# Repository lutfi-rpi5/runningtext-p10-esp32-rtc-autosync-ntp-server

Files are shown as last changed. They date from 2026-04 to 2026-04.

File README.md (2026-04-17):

# Running Text P10 ESP32 + RTC + Auto Sync NTP Server

**Detailed Engineering Design (DED) – Embedded System Engineer**

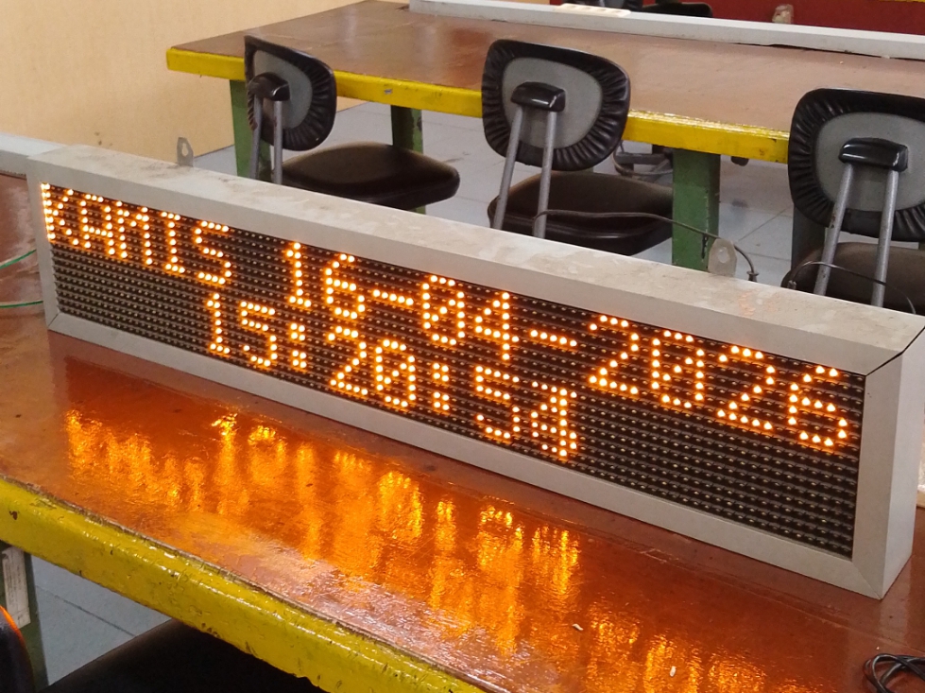
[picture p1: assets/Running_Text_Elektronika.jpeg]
Demo Sistem


---

## 1. Tentang Sistem

Sistem ini adalah **Running Text LED P10 berbasis ESP32** yang dirancang sebagai papan informasi digital cerdas. Keunggulan utamanya adalah ketahanan terhadap gangguan internet: display tetap menampilkan teks berjalan dan waktu dari **RTC (Real-Time Clock)** meskipun jaringan Wi-Fi tidak tersedia. Ketika koneksi internet kembali, sistem akan **secara otomatis menyinkronkan waktu dari server NTP (Network Time Protocol)** dan menyimpannya ke modul RTC, memastikan akurasi waktu yang tinggi tanpa campur tangan pengguna.

Sistem dibangun dengan pendekatan **non-blocking** pada seluruh operasi (Wi-Fi, NTP, display), sehingga running text tetap berjalan lancar tanpa jeda yang mengganggu. Arsitektur modular memisahkan logika display, RTC, sinkronisasi NTP, dan buzzer ke dalam file terpisah, memudahkan pengembangan dan pemeliharaan.

**Target Aplikasi:**

- Papan informasi kampus, sekolah, atau institusi.
- Display jam digital di ruang publik (lobi, koridor).
- Papan pengumuman di bengkel, laboratorium, atau area produksi.
- Sistem signage mandiri dengan ketergantungan internet minimal.

---

## 2. Identitas Programmer

| **Atribut** | **Detail** |
|---|---|
| **Nama** | Muhammad Lutfi Nur Anendi |
| **GitHub** | [lutfi-rpi5](https://github.com/lutfi-rpi5) |
| **Board Target** | ESP32 WROOM-32 (ESP32 Dev Module v1.0.6) |
| **Tanggal Rilis** | 3 April 2026 |
| **Versi Firmware**  | 1.0.0 (Stable) |
| **Lisensi** | MIT |

---

## 3. Fitur Sistem

| **Fitur** | **Deskripsi** |
|---|---|
| **Running Text LED P10** | Mendukung panel P10 *single-color* dengan konfigurasi dimensi yang dapat diatur (`DISPLAYS_ACROSS`, `DISPLAYS_DOWN`). |
| **RTC Offline Mode** | Waktu tetap akurat menggunakan modul RTC DS1302/DS3231 saat tidak ada internet. |
| **Auto Sync NTP Server** | Sinkronisasi waktu otomatis setiap interval tertentu (default 60 menit) ketika Wi-Fi tersedia. |
| **Non-blocking Architecture** | Semua operasi (Wi-Fi, NTP, display) berjalan tanpa memblokir *main loop*, menjamin running text tetap halus. |
| **Fallback Otomatis ke RTC** | Jika NTP gagal atau internet putus, sistem langsung beralih ke RTC tanpa mengganggu tampilan. |
| **Scene Management** | Mendukung dua *scene* utama: **Scene 1 (Running Text)** dan **Scene 2 (Display RTC)** dengan transisi otomatis.|
| **Durasi Tampil RTC Dapat Dikonfigurasi** | Waktu tampil scene RTC dapat diatur dalam milidetik (default 3 menit). |
| **Buzzer Feedback** | Indikator suara untuk *boot*, sinkronisasi berhasil, dan *error*. |
| **Konfigurasi Mudah via Kode** | Semua parameter (SSID, password, zona waktu, kecepatan scroll, dll.) terpusat di file `.ino` dan `.cpp`. |
| **Modular Code** | Pemisahan modul `RunningText`, `RTCAutoSync`, `Buzzer`, dan `virtuabotixRTC` untuk kemudahan *debugging* dan pengembangan. |

---

## 4. Arsitektur Sistem

Diagram blok berikut menggambarkan aliran data dan kontrol utama:

```
+----------------+      +----------------+      +----------------+
|   Internet     |      |   ESP32        |      |   LED Panel    |
|   (NTP Server) |<---->|   (Wi-Fi)      |<---->|   P10          |
+----------------+      +----------------+      +----------------+
                              ^   ^
                              |   |
                              v   v
                         +----------------+
                         |   RTC Module   |
                         |   (DS1302)     |
                         +----------------+
                              ^
                              |
                              v
                         +----------------+
                         |   Buzzer       |
                         |   (Feedback)   |
                         +----------------+
```

**Alur Kerja Sistem:**

1. **ESP32 Boot** – Inisialisasi Serial, Buzzer, RTC, dan Display.
2. **Coba Koneksi Wi-Fi** – Dilakukan secara *non-blocking* setelah *boot delay* (default 0 detik).
3. **Jika Berhasil → Sync NTP** – Waktu dari `pool.ntp.org` diambil, dikonversi ke zona waktu WIB (GMT+7), dan disimpan ke RTC.
4. **Jika Gagal → Gunakan RTC** – Sistem tetap beroperasi dengan waktu yang tersimpan di RTC.
5. **Running Text Berjalan** – Scene teks utama ditampilkan (berulang 1x), lalu beralih ke scene RTC selama durasi tertentu, dan kembali ke scene teks.
6. **Sinkronisasi Berkala** – Setiap interval `ntp_sync_interval` (default 60 menit), sistem kembali mencoba sinkronisasi NTP.

**Penanganan Kegagalan:**

- **Wi-Fi Timeout** – Setelah 60 detik tanpa koneksi, Wi-Fi dimatikan untuk menghemat daya.
- **NTP Failed** – RTC tetap digunakan, dan sinkronisasi dicoba lagi pada interval berikutnya.

---

## 5. Hardware Requirements

| **Komponen** | **Spesifikasi / Catatan** |
|---|---|
| **ESP32** | ESP32 WROOM-32 (disarankan) atau varian ESP32 lain dengan pinout serupa. |
| **LED Panel P10** | *Single-color* (merah/hijau/biru), resolusi 32x16 pixel per panel. |
| **RTC Module** | DS1302 (diuji) atau DS3231 (kompatibel). Pastikan baterai CR2032 terpasang untuk backup. |
| **Power Supply** | 5V DC dengan arus cukup (min. 2A untuk 1-3 panel, lebih besar untuk panel lebih banyak). |
| **Kabel Jumper** | Male-to-female dan female-to-female untuk koneksi ESP32 ↔ P10 ↔ RTC. |
| **Buzzer (Opsional)** | Buzzer aktif LOW 5V. |
| **Konektor** | Header pin 2.54mm untuk koneksi yang rapi. |

---

## 6. Software Requirements

| **Software** | **Versi / Catatan** |
|---|---|
| **Arduino IDE** | 1.8.19 atau lebih baru. |
| **ESP32 Board Package** | **Versi 1.0.6** (wajib). Versi lain mungkin menyebabkan error kompilasi pada library DMD32. |
| **Library DMD32 v1.0** | Instal via Library Manager Arduino IDE. |
| **Library Bawaan ESP32** | `WiFi.h`, `time.h`, `SPI.h`, `Wire.h` (sudah termasuk dalam board package). |
| **Library Lokal (Include)** | `runningtext.h/cpp`, `rtc_autosync.h/cpp`, `virtuabotixRTC.h/cpp`, `buzzer.h/cpp` (sudah ada di repo).  |
| **Fonts** | `SystemFont5x7.h`, `Arial_black_16.h` (termasuk dalam library DMD32). |

---

## 7. Installation

### 7.1 Clone Repository

```bash
git clone https://github.com/lutfi-rpi5/runningtext-p10-esp32-rtc-autosync-ntp-server.git
```
Atau unduh ZIP dari GitHub dan ekstrak.

### 7.2 Install ESP32 Board Package v1.0.6
1. Buka **Arduino IDE** → **File** → **Preferences**.
2. Tambahkan URL berikut ke **Additional Boards Manager URLs**:
```text
https://raw.githubusercontent.com/espressif/arduino-esp32/gh-pages/package_esp32_index.json
```
3. Buka **Tools** → **Board** → **Boards Manager**.
4. Cari **ESP32** by Espressif Systems dan instal **versi 1.0.6**.

### 7.3 Install Library DMD32
1. Buka **Sketch** → **Include Library** → **Manage Libraries**.
2. Cari **DMD32** dan install **versi 1.0**.

### 7.4 Buka Project
1. Buka file `runningtext-p10-esp32-rtc-autosync-ntp-server.ino` di **Arduino IDE**.
2. Pastikan board yang dipilih adalah **ESP32 Dev Module** (atau sesuai board Anda).

### 7.5 Compile & Upload
1. Hubungkan ESP32 ke komputer via USB.
2. Pilih port yang sesuai di **Tools** → **Port**.
3. Klik tombol **Upload**.

---

## 8. Configurations
Seluruh konfigurasi penting terpusat di file utama `.ino` dan file modul terkait. Berikut panduan lengkapnya.

### 8a. Sinkronisasi RTC (NTP Sync Interval)
**Lokasi**: `rtc_autosync.cpp` baris 11-13.

```cpp
const unsigned long ntp_sync_interval = (60 * 60) * 1000;  // 60 menit
const unsigned long ntp_sync_starting_at = (0.1 * 60) * 1000; // 10 detik pertama
```

* `ntp_sync_interval` : Interval sinkronisasi NTP dalam milidetik. Default 1 jam.
* `ntp_sync_starting_at` : Delay awal sebelum sinkronisasi pertama setelah boot. Default 10 detik (untuk memberi waktu koneksi Wi-Fi stabil).

### 8b. Time Zone & Day Offset Setting
**Lokasi**: `rtc_autosync.cpp` baris 9-10.

```cpp
const long gmtOffset_sec = 25200;   // WIB (GMT+7) = 7 * 3600 detik
const int daylightOffset_sec = 0;   // Tidak ada DST di Indonesia
```

* `gmtOffset_sec` : Offset zona waktu dalam detik dari GMT.
    * WIB (GMT+7) = 25200
    * WITA (GMT+8) = 28800
    * WIT (GMT+9) = 32400
* `daylightOffset_sec` : Offset Daylight Saving Time (tidak digunakan di Indonesia).

### 8c. SSID & PASSWORD Setting
**Lokasi**: `rtc_autosync.cpp` baris 8.

```cpp
const char* ssid = "sync-elektro";
const char* password = "12345678";
```
Ganti dengan kredensial Wi-Fi yang tersedia.

### 8d. Jumlah Display Across & Display Down
**Lokasi**: `runningtext.cpp` baris 9.

```cpp
#define DISPLAYS_ACROSS 3   // Jumlah panel horizontal
#define DISPLAYS_DOWN 1     // Jumlah panel vertikal
```
Atur sesuai konfigurasi fisik panel P10 Anda. Sistem akan otomatis menyesuaikan lebar total display (`32 * DISPLAYS_ACROSS` pixel).

### 8e. Ganti Text Utama
**Lokasi**: `runningtext-p10-esp32-rtc-autosync-ntp-server.ino` baris 8-10.

```cpp
String text_utama = "Selamat Datang di Bengkel Jurusan Teknik Elektro | Prodi Teknik Elektronika Politeknik Negeri Sriwijaya Utamakan Keselamatan dan Kesehatan Kerja";
```
Ganti dengan teks yang diinginkan. Gunakan karakter `|` sebagai pemisah jika ingin beberapa bagian teks (tidak memengaruhi animasi, hanya teks biasa).

### 8f. Display Speed
**Lokasi**: `runningtext-p10-esp32-rtc-autosync-ntp-server.ino` baris 12.

```cpp
display.setSpeed(20);
```
* Nilai dalam milidetik, semakin kecil semakin cepat. Rentang tipikal 15–50.

### 8g. Durasi Tampil Scene RTC
**Lokasi**: `runningtext-p10-esp32-rtc-autosync-ntp-server.ino` baris 22-23.

```cpp
display.sceneRTC( tanggal, waktu, (3 * 60) * 1000 ); // 3 menit
```
* Ubah (3 * 60) * 1000 menjadi durasi yang diinginkan dalam milidetik. Contoh:
    * 1 menit = (1 * 60) * 1000
    * 5 menit = (5 * 60) * 1000

---

## 9. Pin Configuration

### 9.1 Panel P10 → ESP32

|**P10 Pin**  |	**ESP32 GPIO** |  **Keterangan**  |
|---|---|---|
|GND | GND |	Ground |
|OE	 | GPIO 22 |Output Enable |
|A	 | GPIO 19 |Address Line A|
|B	 | GPIO 21	 |Address Line B|
|CLK	  | GPIO 18	 |Clock (Shift Register)|
|LAT (STB)|	GPIO 2	 |Latch / Strobe|
|DR (R1)  | GPIO 23	 |Data Red (untuk panel single-color)|

**Catatan**: Untuk panel *single-color*, hanya gunakan pin **R1** (DR). Pin **G1** (hijau) dan **B1** (biru) tidak digunakan.

### 9.2 RTC (DS1302) → ESP32
|**DS1302 Pin** |	**ESP32 GPIO**  |
|---|---|
|CLK	 | GPIO 25 |
|DAT	 | GPIO 26 |
|RST	 | GPIO 27 |
|VCC	 |5V (atau 3.3V) |
|GND	 | GND |

### 9.3 Buzzer → ESP32
|Buzzer Pin	 | ESP32 GPIO  |
|---|---|
|+ (Positif) |	GPIO 33 |
|- (Negatif) |	GND |

**Catatan**: Buzzer dikonfigurasi active *LOW* (menyala saat pin diberi logika `LOW`). Jika menggunakan buzzer langsung tanpa relay, ubah logika di `buzzer.cpp` baris 4-5 sesuai komentar.

---

## 10. Struktur Proyek
```text
runningtext-p10-esp32-rtc-autosync-ntp-server/
│
├── runningtext-p10-esp32-rtc-autosync-ntp-server.ino   # Main sketch
├── runningtext.h / .cpp                                # Modul display & scene
├── rtc_autosync.h / .cpp                               # Modul RTC & NTP sync
├── virtuabotixRTC.h / .cpp                             # Library RTC DS1302
├── buzzer.h / .cpp                                     # Modul buzzer
├── fonts/
│   ├── SystemFont5x7.h
│   └── Arial_black_16.h
├── build/                                              # Compiled firmware (opsional)
└── README.md
```

---

## 11. Troubleshooting

| **Masalah** | **Solusi** |
|---|---|
| **Display tidak menyala / blank** | - Periksa koneksi kabel P10 (OE, CLK, LAT, DR).<br>- Pastikan power supply 5V mencukupi (gunakan adaptor eksternal, bukan USB ESP32). |
| **Teks berjalan terlalu cepat/lambat** | Ubah nilai `display.setSpeed()` di file `.ino`. Semakin kecil nilai, semakin cepat. |
| **Waktu RTC tidak akurat / reset** | - Ganti baterai CR2032 pada modul RTC.<br>- Pastikan sinkronisasi NTP berhasil (lihat Serial Monitor). |
| **Wi-Fi tidak terhubung** | - Periksa SSID dan password di `rtc_autosync.cpp`.<br>- Pastikan sinyal Wi-Fi cukup kuat.<br>- Tambahkan `delay(5000)` setelah `WiFi.begin()`. |
| **ESP32 bootloop (restart terus pada saat di Serial Monitor)** | **Solusi Umum:** <br>- Buka Serial Monitor (baud 115200) dan periksa pesan error terakhir.<br>- Coba *flash* ulang firmware sambil menekan tombol **BOOT**.<br>- Pastikan power supply stabil (3.3V/5V) dan tidak ada korsleting pada pin GPIO.<br>- Hapus flash sepenuhnya dengan `esptool.py erase_flash` lalu upload ulang.<br><br>**Solusi Alternatif (Khusus Windows User – Pembersihan Cache & Instal Ulang Board Package):** <br>1. Buka **Board Manager** di Arduino IDE, cari **ESP32** by Espressif Systems, lalu klik **Remove** untuk menghapus versi yang terpasang (misal v1.0.6).<br>2. Tutup **semua jendela** Arduino IDE yang sedang berjalan.<br>3. Tekan tombol <kbd>Win</kbd> + <kbd>R</kbd>, ketik `%TEMP%` lalu tekan **Enter**. Pilih semua file dan folder (<kbd>Ctrl</kbd> + <kbd>A</kbd>) kemudian hapus permanen dengan <kbd>Shift</kbd> + <kbd>Delete</kbd>.<br>4. Ulangi langkah 3 untuk direktori **`temp`** dan **`PREFETCH`** (ketik masing‑masing pada dialog **Run**).<br>5. **Restart** komputer/laptop.<br>6. Buka kembali Arduino IDE, instal ulang **ESP32 Board Package versi 1.0.6** melalui Board Manager.<br>7. Coba upload ulang sketch. |
| **Kompilasi error "DMD was not declared"** | Pastikan library **DMD32** sudah terinstal. Jika tetap error, coba hapus dan instal ulang library. |
| **ESP32 tidak terdeteksi di Arduino IDE** | - Tekan tombol BOOT saat uploading.<br>- Instal driver USB-to-Serial (CP210x atau CH340). |

## 12. Pengembangan Lebih Lanjut
* **OTA Update**: Tambahkan fitur Over-the-Air untuk update firmware via Wi-Fi.
* **Multi-Scene**: Tambahkan lebih banyak scene (misal: suhu, kelembaban, atau informasi dari sensor).
* **Web Config**: Buat portal web sederhana untuk mengubah teks dan pengaturan tanpa recompile.
* **E-paper / OLED**: Integrasi display sekunder untuk informasi status sistem.

---

## 13. Kontribusi
Kontribusi dalam bentuk pull request atau issue sangat diterima. Pastikan kode mengikuti gaya penulisan yang konsisten dan terdokumentasi dengan baik.

## 14. Lisensi
Proyek ini dilisensikan di bawah **MIT License**. Silakan gunakan, modifikasi, dan distribusikan sesuai kebutuhan.

**Dokumentasi ini disusun berdasarkan analisis menyeluruh terhadap kode sumber, struktur proyek, dan best practice _embedded system engineering_. Untuk pertanyaan lebih lanjut, silakan buka _issue_ di repositori GitHub.**

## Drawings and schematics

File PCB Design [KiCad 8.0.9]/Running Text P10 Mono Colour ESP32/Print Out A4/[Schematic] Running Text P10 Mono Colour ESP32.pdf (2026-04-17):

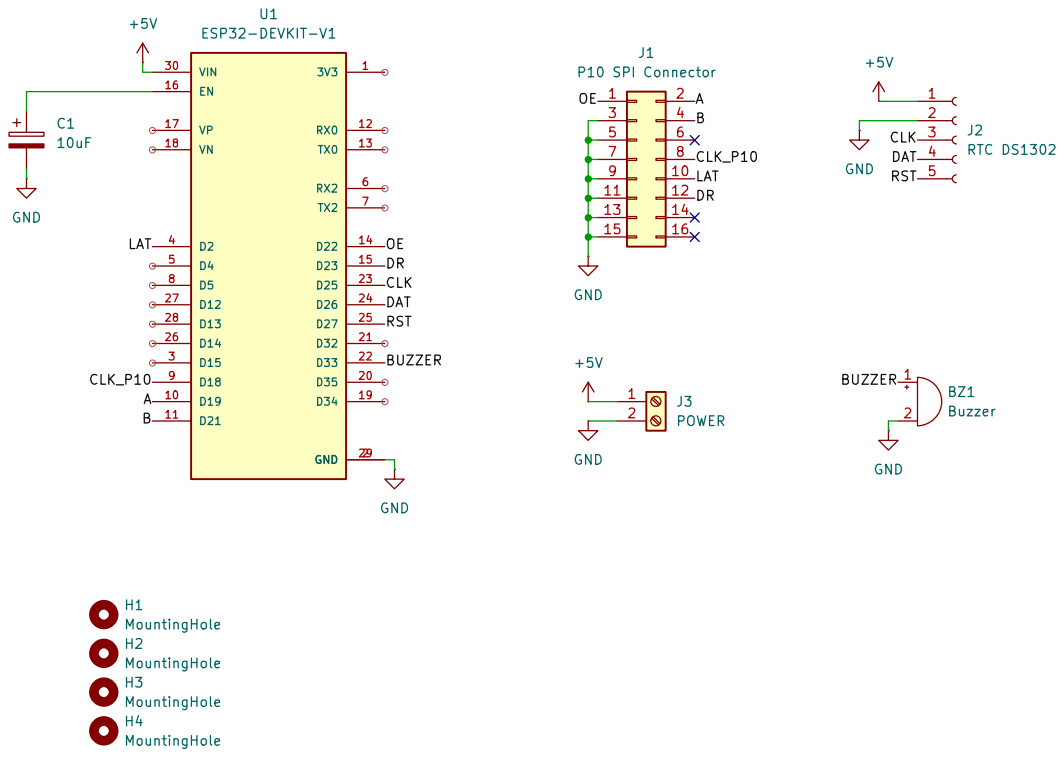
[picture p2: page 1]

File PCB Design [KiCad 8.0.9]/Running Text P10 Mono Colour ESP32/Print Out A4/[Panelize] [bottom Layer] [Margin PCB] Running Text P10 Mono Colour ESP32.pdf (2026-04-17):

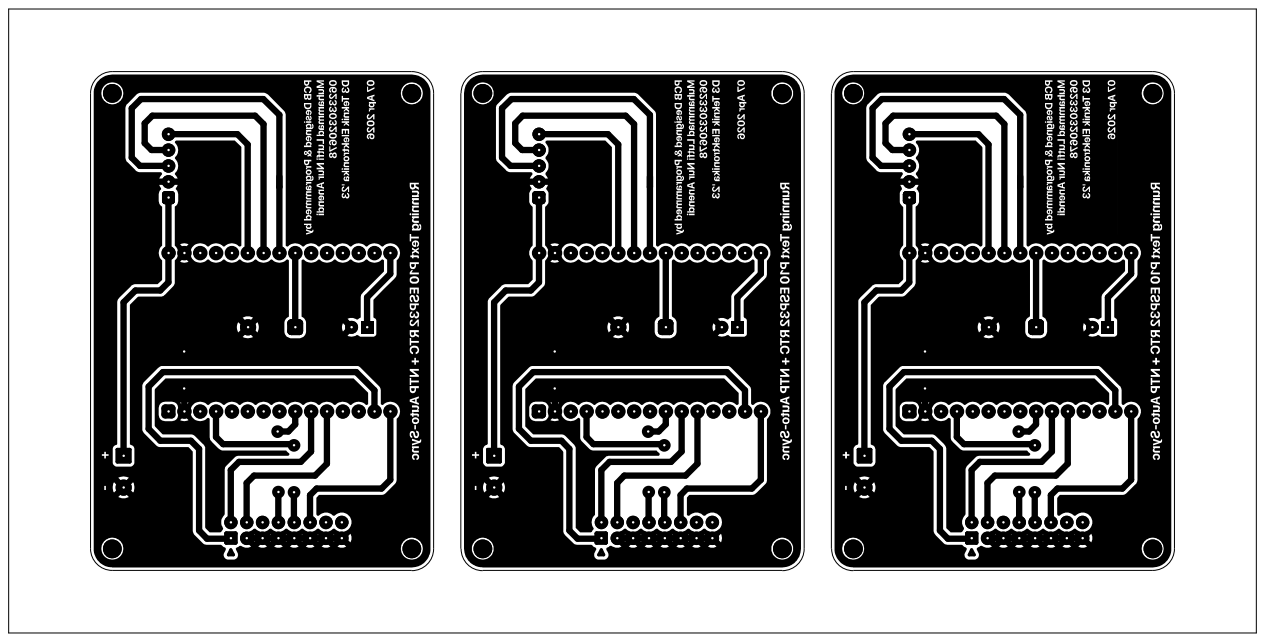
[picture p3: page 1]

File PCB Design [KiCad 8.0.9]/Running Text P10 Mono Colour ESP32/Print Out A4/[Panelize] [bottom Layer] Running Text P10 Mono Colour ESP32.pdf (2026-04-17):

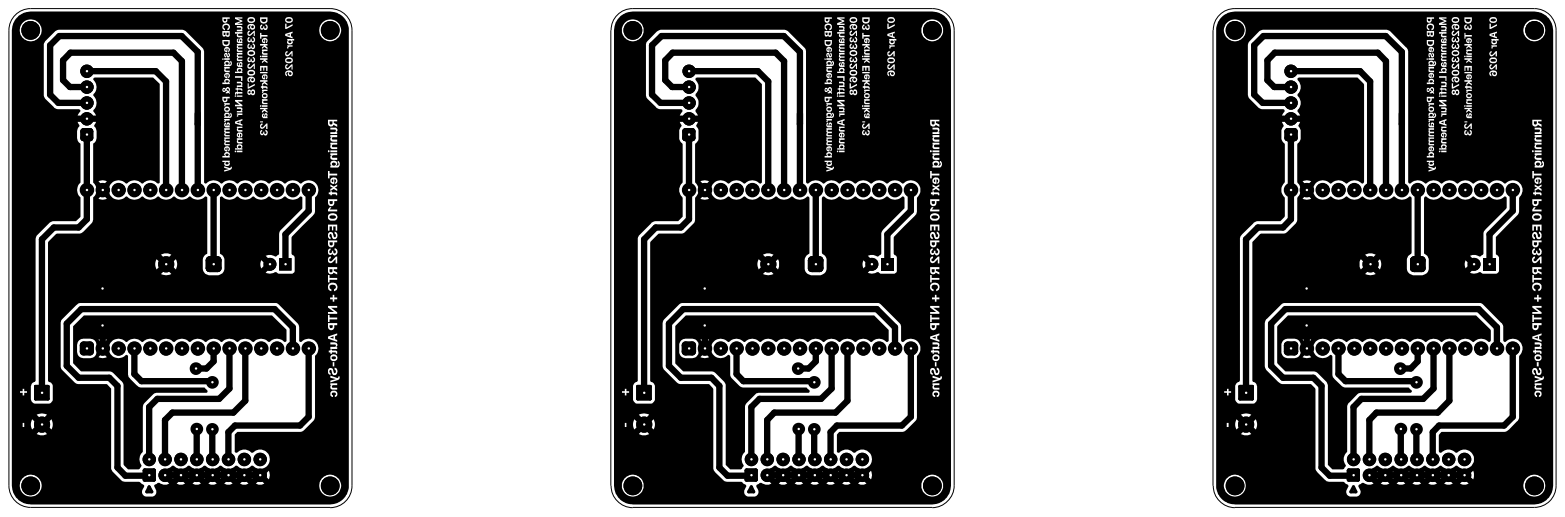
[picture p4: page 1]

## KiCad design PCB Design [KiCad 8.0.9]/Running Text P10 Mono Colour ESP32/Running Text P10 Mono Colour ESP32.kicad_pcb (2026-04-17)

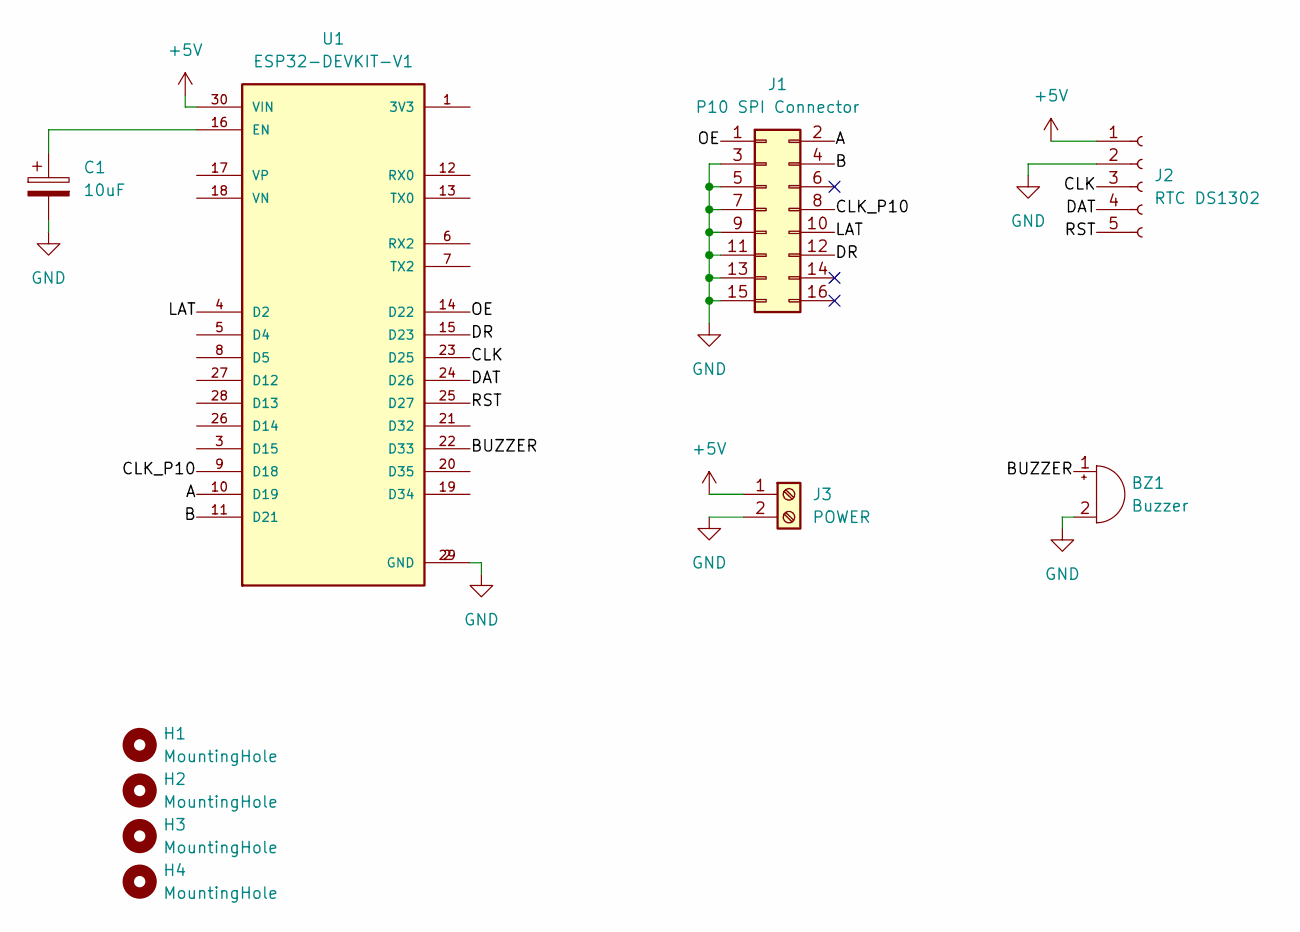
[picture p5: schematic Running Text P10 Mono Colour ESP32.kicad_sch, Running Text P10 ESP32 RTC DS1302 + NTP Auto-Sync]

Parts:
BZ1: Buzzer; Buzzer_12x9.5RM7.6
C1: 10uF; CP_Radial_D5.0mm_P2.50mm
H1, H2, H3, H4: MountingHole; MountingHole_3mm
J1: P10 SPI Connector; IDC-Header_2x08_P2.54mm_Vertical
J2: RTC DS1302; PinHeader_1x05_P2.54mm_Vertical
J3: POWER; TerminalBlock_RND_205-00232_1x02_P5.08mm_Horizontal
U1: ESP32-DEVKIT-V1; ESP32_DEVKIT_V1; PARTREV N/A

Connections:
+5V: J2.1, J3.1, U1.30 (VIN)
/A: J1.2, U1.10 (D19)
/B: J1.4, U1.11 (D21)
/BUZZER: BZ1.1 (+), U1.22 (D33)
/CLK: J2.3, U1.23 (D25)
/CLK_P10: J1.8, U1.9 (D18)
/DAT: J2.4, U1.24 (D26)
/DR: J1.12, U1.15 (D23)
/LAT: J1.10, U1.4 (D2)
/OE: J1.1, U1.14 (D22)
/RST: J2.5, U1.25 (D27)
GND: BZ1.2 (-), C1.2, J1.3, J1.5, J1.7, J1.9, J1.11, J1.13, J1.15, J2.2, J3.2, U1.2 (GND), U1.29 (GND)
unnamed: C1.1, U1.16 (EN)

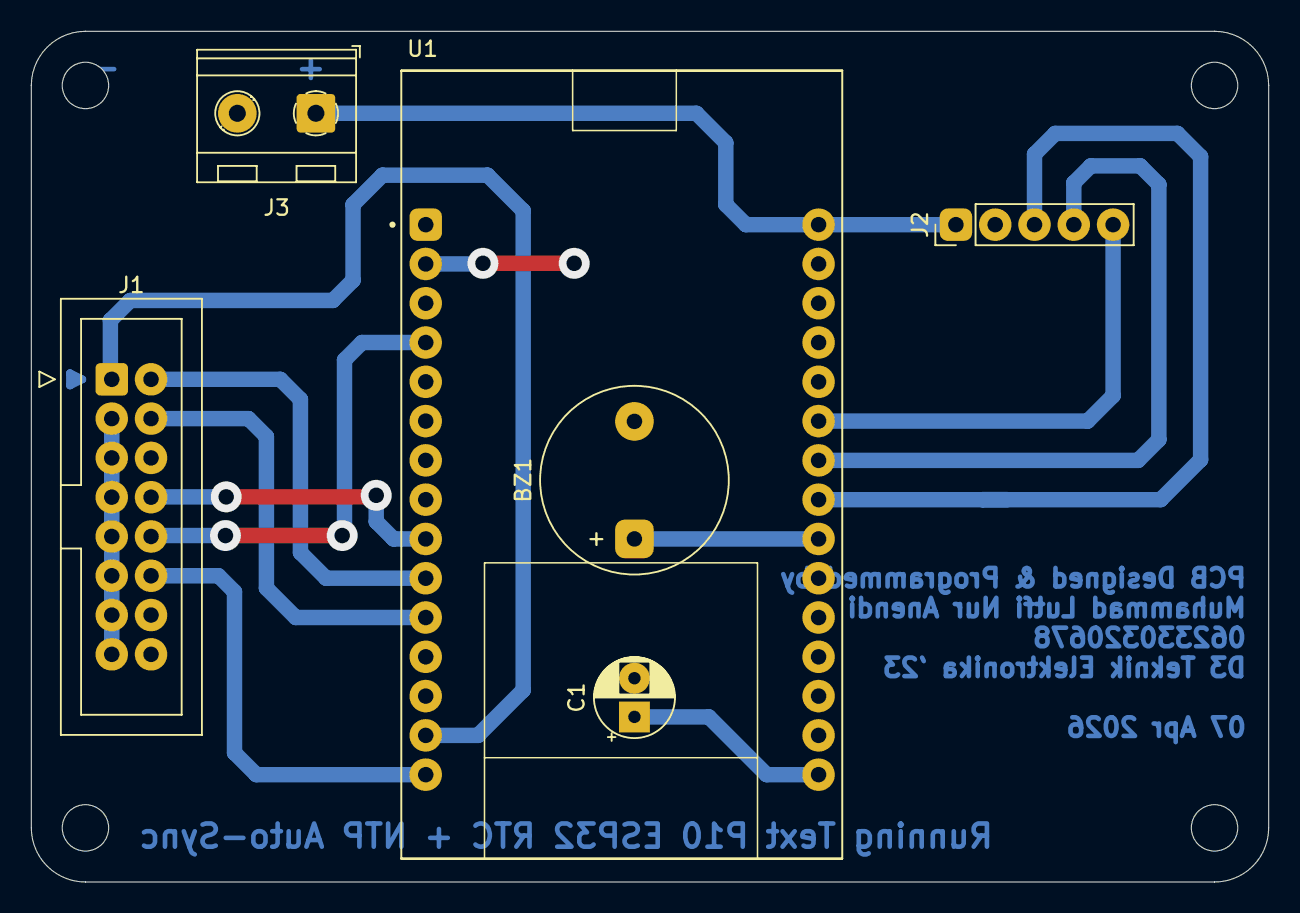
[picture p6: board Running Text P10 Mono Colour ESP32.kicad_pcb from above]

Board: 2 copper layers, 80.0 x 55.0 mm, 10 parts (0 on the bottom side), 13 nets.

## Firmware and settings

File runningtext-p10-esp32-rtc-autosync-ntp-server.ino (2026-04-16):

/*
PROGRAM NAME :
"Running Text P10 ESP32 with RTC DS1302 (Auto Sync WIB)"

DATE          : 03-4-2026
AUTHOR        : Muhammad Lutfi Nur Anendi
BOARD         : ESP32 WROOM-32
BOARD VERSION : ESP32 Dev Module v1.0.6
*/

#include "runningtext.h"
#include "rtc_autosync.h"
#include "buzzer.h"

RunningText display;
RTCAutoSync main_rtc;

// String space_text = "              ";

String text_utama =
// "Selamat Datang di Bengkel Jurusan Teknik Elektro";
"Selamat Datang di Bengkel Jurusan Teknik Elektro  |  Prodi Teknik Elektronika              Politeknik Negeri Sriwijaya              Utamakan Keselamatan dan Kesehatan Kerja";

void setup() {

  Serial.begin(115200); 

  delay(500);

  // digitalWrite(33, HIGH);

  buzzer.begin(33);
  main_rtc.begin();
  display.begin();

  // DISPLAY SPEED
  display.setSpeed(20);

  Serial.println("[MAIN] runningtext_p10_esp32_rtc_autosync_ntp_server");
  Serial.println("[MAIN] System is Starting...");
  Serial.println("[MAIN] _____________________________________________");
  buzzer.beepLong(1000);
}

void loop() {

  // main_rtc.update();

  static uint8_t scene = 0;
  static unsigned long rtc_timer = 0;

  static String waktu;
  static String tanggal;

  // Update RTC tiap 1 detik
  if (millis() - rtc_timer > 1000) {

    main_rtc.update();

    waktu   = main_rtc.getTimeString();
    tanggal = main_rtc.getDateString();

    rtc_timer = millis();
  }

  // Scene 1 : Running Text
  if (scene == 0) {

    display.sceneText(text_utama, 1);
    scene = 1;
  }

  // Pindah ke Scene 2
  else if (scene == 1 && display.isFinished()) {

    display.sceneRTC(
      tanggal,
      waktu,
      (3 * 60) * 1000 //DURASI TAMPIL SCENE RTC
    );

    scene = 2;
  }

  // Scene 2 : RTC Live Update
  else if (scene == 2) {

    display.updateRTC(
      tanggal,
      waktu
    );

    if (display.isFinished()) {
      scene = 0;
    }
  }

  display.update();
  buzzer.update();
}

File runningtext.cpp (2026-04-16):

#include "runningtext.h"
#include "fonts/SystemFont5x7.h"
#include "fonts/Arial_black_16.h"
#include <Ticker.h>

/*
===========================================================
RUNNING TEXT ENGINE
-----------------------------------------------------------
Fungsi :
- Running text P10
- Scene management
- RTC display
- Hardware timer scan DMD
===========================================================
*/

/*
GND – GND
OE – D22
A – D19
B – D21
CLK – D18
LAT – D2
DR – D23
VCC – VP
GND – EN
*/


#define DISPLAYS_ACROSS 3
#define DISPLAYS_DOWN 1

DMD* dmd;

// hw_timer_t* timer = NULL;
Ticker displayTicker;

uint16_t scrollSpeed = 30;

/*
===========================================================
TIMER INTERRUPT
-----------------------------------------------------------
Digunakan untuk scan display P10
Harus cepat dan ringan
===========================================================
*/
void RunningText::triggerScan() {
  dmd->scanDisplayBySPI();
}
// void IRAM_ATTR RunningText::triggerScan() {
//   dmd->scanDisplayBySPI();
// }
// void IRAM_ATTR RunningText::triggerScan() {
//   if (dmd) {
//     dmd->scanDisplayBySPI();
//   }
// }


/*
===========================================================
BEGIN
-----------------------------------------------------------
Inisialisasi DMD dan Timer Hardware
===========================================================
*/
void RunningText::begin() {

  Serial.println("[DISPLAY] Init Running Text");

  dmd = new DMD(DISPLAYS_ACROSS, DISPLAYS_DOWN);

  displayTicker.attach_ms(2, RunningText::triggerScan);

  dmd->clearScreen(true);

  Serial.println("[DISPLAY] Display Ready");
}

// void RunningText::begin() {

//   Serial.println("[DISPLAY] Init Running Text");

//   dmd = new DMD(DISPLAYS_ACROSS, DISPLAYS_DOWN);

//   delay(10);

//   uint8_t cpuClock = ESP.getCpuFreqMHz();

//   Serial.print("[DISPLAY] CPU Clock : ");
//   Serial.println(cpuClock);

//   // timer = timerBegin(0, cpuClock, true);
//   // timerAttachInterrupt(timer, &RunningText::triggerScan, true);
//   // timerAlarmWrite(timer, 300, true);
//   // timerAlarmEnable(timer);

//   timer = timerBegin(0, 80, true);
//   timerAttachInterrupt(timer, &RunningText::triggerScan, true);
//   timerAlarmWrite(timer, 2000, true);
//   timerAlarmEnable(timer);

//   dmd->clearScreen(true);

//   Serial.println("[DISPLAY] Display Ready");
// }

/*
===========================================================
SET SPEED
-----------------------------------------------------------
Mengatur kecepatan running text
===========================================================
*/
void RunningText::setSpeed(uint16_t speed) {

  scrollSpeed = speed;

  Serial.print("[DISPLAY] Scroll Speed : ");
  Serial.println(scrollSpeed);
}

/*
===========================================================
SCENE TEXT
-----------------------------------------------------------
Menampilkan running text
===========================================================
*/
void RunningText::sceneText(String text, uint8_t repeat) {

  Serial.println("[DISPLAY] Scene Running Text");

  textScene = text;
  repeatTarget = repeat;
  repeatCount = 0;

  sceneInit = false;   // reset init

  currentScene = 1;
}

void RunningText::sceneRTC(String baris1, String baris2, uint32_t duration) {

  Serial.println("[DISPLAY] Scene RTC");

  rtcLine1 = baris1;
  rtcLine2 = baris2;

  sceneDuration = duration;
  sceneTimer = millis();

  sceneInit = false;   // reset init

  currentScene = 2;

  dmd->clearScreen(true);
}

/*
===========================================================
UPDATE
-----------------------------------------------------------
Scene manager
===========================================================
*/
void RunningText::update() {

  if (currentScene == 1) drawText();
  if (currentScene == 2) drawRTC();
}

/*
===========================================================
DRAW TEXT
-----------------------------------------------------------
Menampilkan running text
===========================================================
*/
void RunningText::drawText() {

  static unsigned long timer = 0;
  // static char buffer[512];
  char buffer[256];

  if (!sceneInit) {

    Serial.println("[DISPLAY] Init Running Text Scene");

    dmd->clearScreen(true);
    dmd->selectFont(Arial_Black_16);

    textScene.toCharArray(buffer, textScene.length() + 1);

    dmd->drawMarquee(
      buffer,
      strlen(buffer),
      (32 * DISPLAYS_ACROSS) - 1,
      0
    );

    timer = millis();   // reset timer
    sceneInit = true;
  }

  if (millis() - timer > scrollSpeed) {

    bool ret = dmd->stepMarquee(-1, 0);

    if (ret) {

      repeatCount++;

      Serial.print("[DISPLAY] Repeat : ");
      Serial.println(repeatCount);

      if (repeatCount >= repeatTarget) {

        Serial.println("[DISPLAY] Running Text Scene Finished");

        currentScene = 0;
        sceneInit = false;
        return;
      }

      textScene.toCharArray(buffer, textScene.length() + 1);

      dmd->drawMarquee(
        buffer,
        strlen(buffer),
        (32 * DISPLAYS_ACROSS) - 1,
        0
      );
    }

    timer = millis();
  }
}

void RunningText::drawRTC() {

  if (!sceneInit) {

    Serial.println("[DISPLAY] Init RTC Scene");

    dmd->clearScreen(true);
    sceneInit = true;
  }

  if (millis() - sceneTimer > sceneDuration) {

    Serial.println("[DISPLAY] RTC Scene Finished");

    currentScene = 0;
    sceneInit = false;
    return;
  }

  dmd->selectFont(System5x7);

  int width1 = rtcLine1.length() * 6;
  int width2 = rtcLine2.length() * 6;

  // int x1 = (128 - width1) / 2;
  // int x2 = (128 - width2) / 2;

  int x1 = (32 * DISPLAYS_ACROSS - width1) / 2;
  int x2 = (32 * DISPLAYS_ACROSS - width2) / 2;

  char line1[64];
  char line2[64];

  rtcLine1.toCharArray(line1, rtcLine1.length() + 1);
  rtcLine2.toCharArray(line2, rtcLine2.length() + 1);

  dmd->drawString(x1, 0, line1, rtcLine1.length(), GRAPHICS_NORMAL);
  dmd->drawString(x2, 8, line2, rtcLine2.length(), GRAPHICS_NORMAL);
}

/*
===========================================================
UPDATE RTC
-----------------------------------------------------------
Update text RTC realtime
===========================================================
*/
void RunningText::updateRTC(String baris1, String baris2) {

  rtcLine1 = baris1;
  rtcLine2 = baris2;
}

/*
===========================================================
IS FINISHED
-----------------------------------------------------------
Cek apakah scene selesai
===========================================================
*/
bool RunningText::isFinished() {
  return currentScene == 0;
}

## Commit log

2026-04-17 add PCB Design KiCad 8.0.9
    [Running Text P10 Mono Colour ESP32.kicad_pcb, Running Text P10 Mono Colour ESP32.kicad_sch]
2026-04-17 add Schematic and PCB Print Out Sheet KiCad 8.0.9
